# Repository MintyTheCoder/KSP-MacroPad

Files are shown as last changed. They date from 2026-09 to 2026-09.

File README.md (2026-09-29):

# KSP MacroPad

A custom macropad built for Kerbal Space Program, made for Hack Club's Stardance Challenge.

16 macro keys and 2 rotary encoders on a custom PCB, driven by a Seeed XIAO RP2040. The keys don't send keystrokes. They trigger full flight procedures (launch, gravity turn, circularize, rendezvous, suicide burn, an interplanetary autopilot) that a companion KSP mod runs inside the game. The mod talks to the pad over USB serial, and sends state back for per-key RGB LEDs, underglow, and a 128x32 OLED.

The key matrix is read through a resistor ladder on 4 ADC pins instead of 8 GPIO pins, which is what makes everything fit on the XIAO's 11 pins.

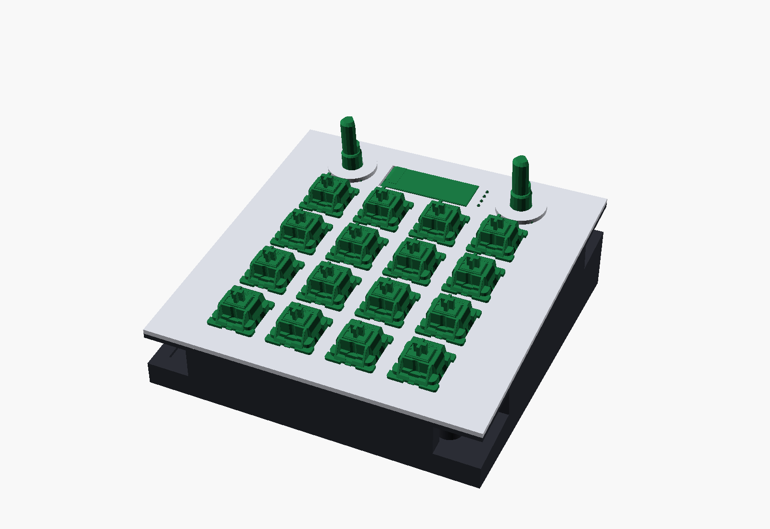
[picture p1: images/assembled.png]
Assembled macropad


## Hardware

- Seeed XIAO RP2040
- 16 MX switches in a 4x4 grid (20 mm pitch), read as an analog matrix on A0 to A3
- 2 EC11 rotary encoders (left on D10/D9, right on D7/D8)
- 20 SK6812 MINI-E RGB LEDs on D6: 16 per-key backlights and 4 underglow
- 0.91" SSD1306 128x32 OLED over I2C (SDA D4, SCL D5)
- 100 x 100 mm 2-layer PCB
- 3D-printed case tilted 7°, with the plate held on by magnets

| | |
|---|---|
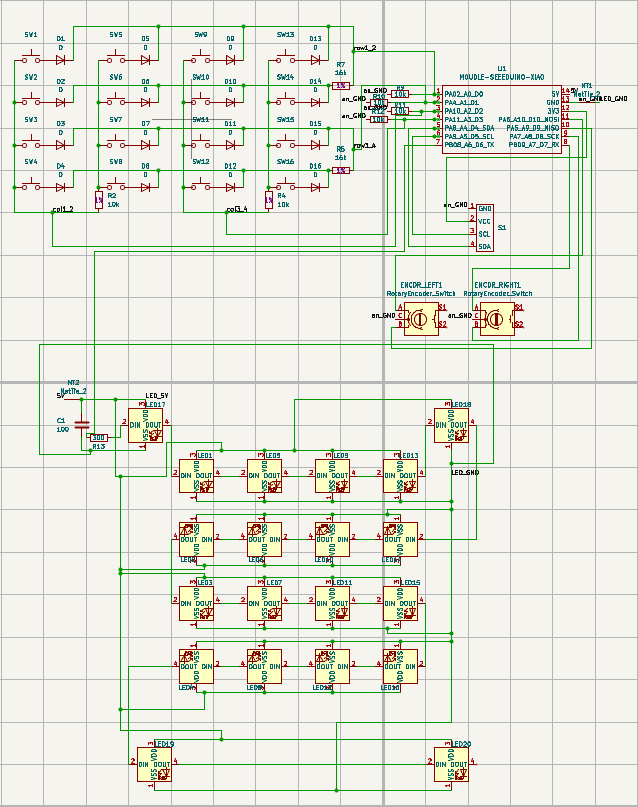
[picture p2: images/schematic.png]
Schematic
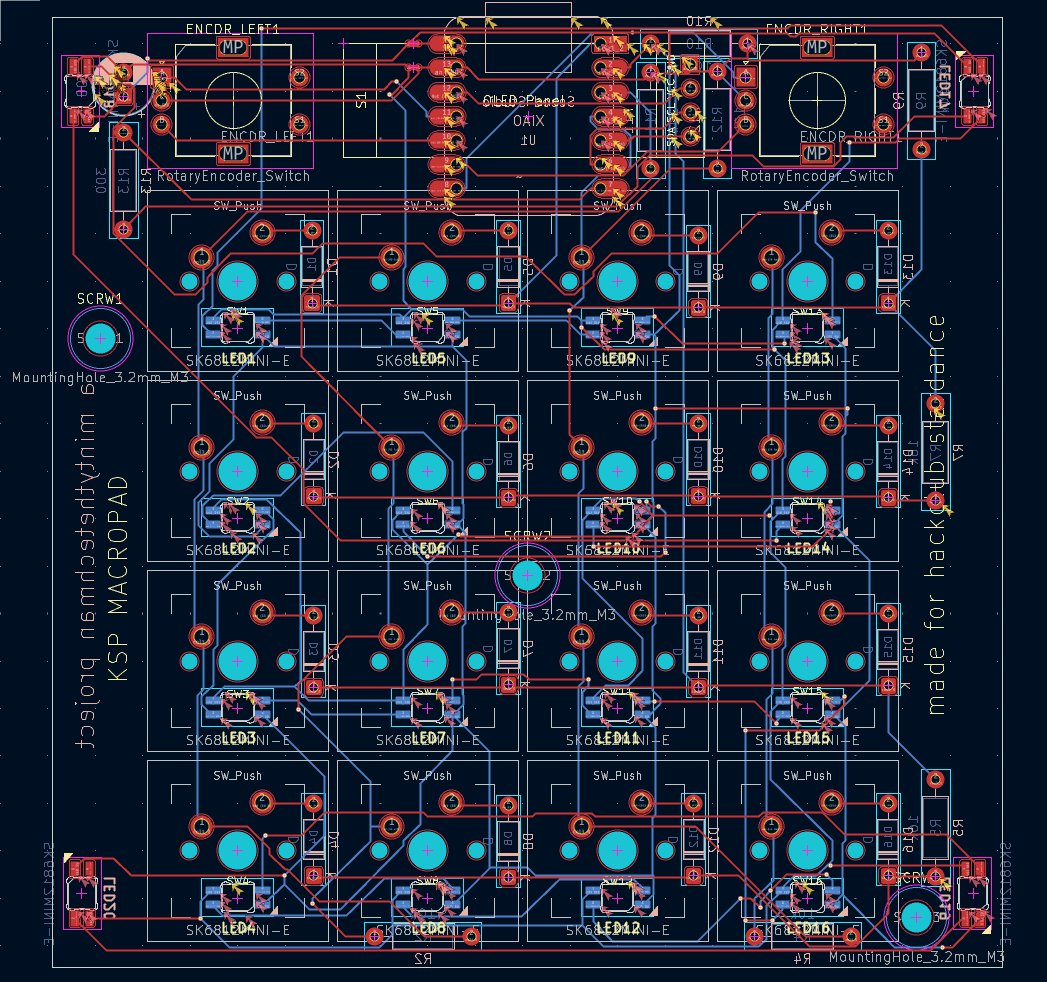
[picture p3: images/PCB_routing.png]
PCB routing
|  |  |
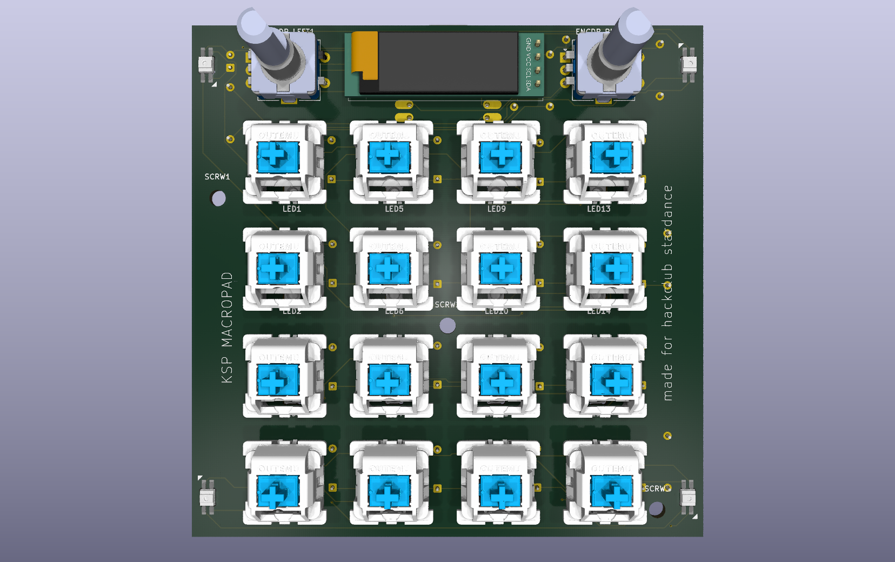
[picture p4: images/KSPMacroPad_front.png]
PCB front
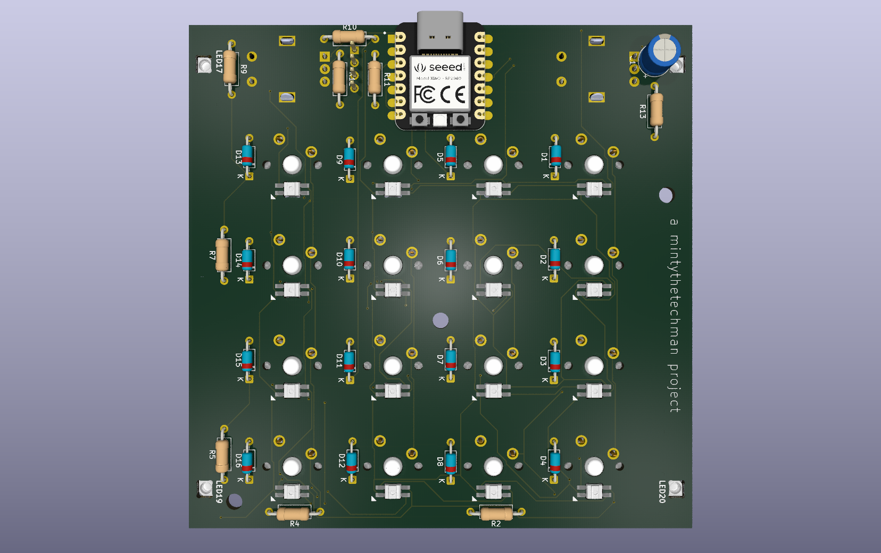
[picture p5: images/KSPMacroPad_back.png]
PCB back
|  |  |

### How the analog matrix works

A normal 4x4 matrix needs 8 pins, and after the encoders, OLED and LEDs there were only 4 left. So each pin carries two lines:

- A2 and A3 each drive two column lines, one straight and one through a 10k resistor.
- A0 and A1 each read two row lines, one straight and one through a 16k resistor, into a 10k pulldown.

The firmware drives one column pin high at a time and reads both row pins. A pressed key puts one of four voltages on its row pin depending on which resistors are in its path:

| Column path | Row path | Row pin voltage |
|---|---|---|
| 10k | 16k | 0.70 to 0.82 V |
| direct | 16k | 0.98 to 1.13 V |
| 10k | direct | 1.28 to 1.45 V |
| direct | direct | 2.62 to 2.85 V |

Those ranges cover 1% resistors across the full 1N4148 diode drop range, and every band has at least 0.15 V of margin to the next, so all 16 keys decode reliably.

## Case

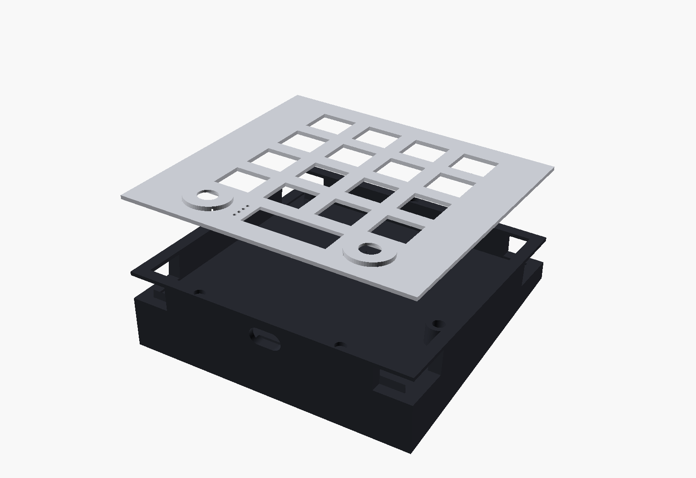
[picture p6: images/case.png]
Case


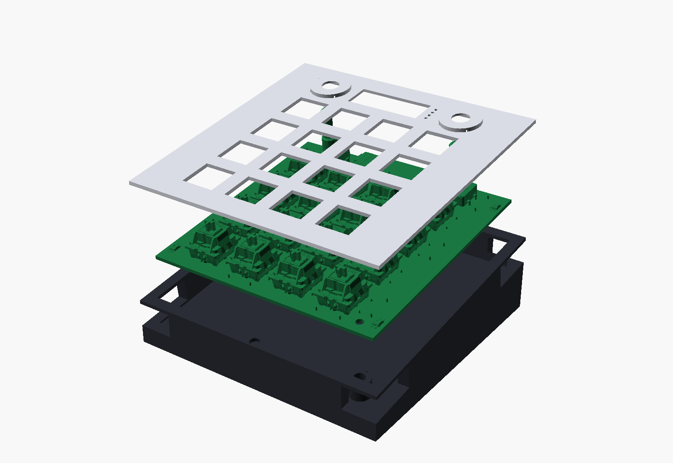
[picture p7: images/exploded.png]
Exploded view


- The board and plate are rotated 7° as one rigid unit on a wedge floor. The bottom stays flat on the desk.
- The plate sits at the MX standard 5.0 mm above the PCB, with 14 mm switch cutouts.
- The encoders come through round holes in raised collars, and the OLED window matches the screen glass.
- The PCB mounts on 3 standoffs with M3 heat-set inserts. The standoffs are perpendicular to the board, with relief notches where parts on the back of the board sit close.
- The plate is held on by 3 pairs of 4 mm magnets, so there are no screws on top.
- The USB-C opening is sized for the plug body and lines up with the tilted connector.
- Underglow notches wrap each corner so the LED light reaches the desk.
- Overall size: 110.4 x 109.8 x 34.2 mm.

The case is fully parametric in [CAD/ksp_macropad_case.scad](CAD/ksp_macropad_case.scad), and it was checked for interference against the real board's STEP model.

## Key Layout

| ID | Macro | ID | Macro |
|---|---|---|---|
| `0x00` | Launch sequence | `0x08` | Docking prep |
| `0x01` | Auto gravity turn | `0x09` | Landing prep |
| `0x02` | Circularize | `0x0A` | Suicide burn arm (hold 1 s) |
| `0x03` | Time warp to next event | `0x0B` | Precision input toggle (encoder mode 2) |
| `0x04` | Intercept | `0x0C` | Transmit science |
| `0x05` | Orbit sync | `0x0D` | Resource monitor |
| `0x06` | Rendezvous prep | `0x0E` | Auxiliary toggle (encoder mode 3) |
| `0x07` | Deorbit burn | `0x0F` | Autopilot |

Macros that fly the vessel queue up: press CIRCULARIZE while AUTO GRAVITY TURN is still flying and it starts as soon as the turn finishes. The OLED shows the active macro and what's queued next.

### Encoder modes

| Mode | Left encoder | Right encoder |
|---|---|---|
| 1: Normal | Throttle | Time warp |
| 2: Precision | Target throttle % | Target heading |
| 3: Auxiliary | Camera zoom | RCS thrust limit % |

## The KSP Mod

The mod ([mod/KSPMacropad](mod/KSPMacropad)) is a C# plugin for KSP 1.12. It:

- finds the pad automatically by listening for its hello packet on every COM port, and reconnects if it's unplugged
- runs all the macros, including a Lambert-solver transfer planner for AUTOPILOT and a closed-loop suicide burn
- drives every key LED and the underglow from live game state (resources, comms, upcoming maneuver nodes, time warp)
- detects MechJeb, Principia, FAR and Kerbalism, and disables the macros that would conflict with them

To install it, build the project in Visual Studio (.NET Framework 4.8) and copy `KSPMacropad.dll` into `GameData/KSPMacropad/Plugins/`. Optional settings go in `KSPMacropad.cfg` next to the DLL:

```
port = COM5
allow_with_mechjeb = true
```

## Serial Protocol

The firmware turns on a second USB CDC data port (in `boot.py`) alongside the REPL console.

**Pad to mod** (6 bytes): `[0x44, type, id, data_hi, data_lo, 0x77]`
- `type 0x01`: key press, `id` = key ID
- `type 0x02`: encoder turn, `id` = `(mode << 4) | encoder` (1 = left, 2 = right), data = signed 16-bit detent steps
- `type 0x03`: hello, sent every second so the mod can find the right port
- `type 0x04`: resync, asks the mod to resend every LED state after a lost connection

**Mod to pad** (5 bytes): `[0x77, id, state, data, 0x44]`
- `0x00` to `0x0F`: key LED state
- `0x10` to `0x13`: underglow state
- `0x14`: heartbeat (the pad shows `NO CONN` after 3 s without one)
- `0x15`: live throttle %
- `0x16`: live warp rate, as `data x 10^(state & 0x0F)`, with bit 7 of `state` set for physics warp
- `0x17` to `0x19`: active macro, next queued macro, queue length

LED state values are defined in `led_states.py` (firmware) and `LEDStates.cs` (mod), and the two have to stay in sync.

## Flashing the Firmware

1. Install [CircuitPython](https://circuitpython.org/board/seeeduino_xiao_rp2040/) on the XIAO RP2040.
2. Copy these libraries from the Adafruit CircuitPython bundle into `CIRCUITPY/lib/`:
   - `neopixel`
   - `adafruit_display_text`
   - `adafruit_displayio_ssd1306`
3. Copy `boot.py`, `code.py` and `led_states.py` from [Firmware/](Firmware/) to the root of `CIRCUITPY`.
4. Power-cycle the board (not just a soft reload) so `boot.py` can turn on the USB data port.

## Bill of Materials

| Qty | Part | Reference | Notes |
|---|---|---|---|
| 1 | Seeed XIAO RP2040 | U1 | |
| 16 | MX switches | SW1 to SW16 | |
| 16 | DSA 1U keycaps | | |
| 16 | 1N4148 diodes, through-hole | D1 to D16 | |
| 20 | SK6812 MINI-E RGB LEDs | LED1 to LED20 | reverse mount |
| 2 | EC11 rotary encoders, 20 mm shaft | ENCDR_LEFT1, ENCDR_RIGHT1 | |
| 1 | 0.91" 128x32 SSD1306 OLED, I2C | S1 | pinout GND, VCC, SCL, SDA |
| 1 | 100 µF electrolytic capacitor | C1 | LED supply |
| 2 | 10k resistor, 1% | R2, R4 | matrix columns |
| 2 | 16k resistor, 1% | R5, R7 | matrix rows |
| 4 | 10k resistor | R9 to R12 | ADC pulldowns |
| 1 | 300 Ω resistor | R13 | LED data line |
| 3 | M3 x 16 mm screws | | PCB to case |
| 3 | M3 x 5 x 4 mm heat-set inserts | | |
| 6 | 4 x 1 mm disc magnets | | plate retention, glued in pairs |
| 1 | PCB | | [production/gerbers.zip](production/gerbers.zip) |
| 1 | Case bottom, 3D printed | | [production/case_bottom.stl](production/case_bottom.stl) |
| 1 | Top plate, 3D printed | | [production/case_top_plate.stl](production/case_top_plate.stl) |

## Repository Layout

- [CAD/](CAD/): OpenSCAD case source, case STEP files, and the full assembled STEP
- [PCB/](PCB/): KiCad 10 project, board STEP, and footprint/3D model libraries
- [Firmware/](Firmware/): CircuitPython firmware
- [mod/](mod/): KSP C# plugin
- [production/](production/): gerbers, printable case STLs, and the firmware files
- [images/](images/): renders and screenshots

## Tools

- KiCad 10
- OpenSCAD
- CircuitPython
- Visual Studio
- Kerbal Space Program

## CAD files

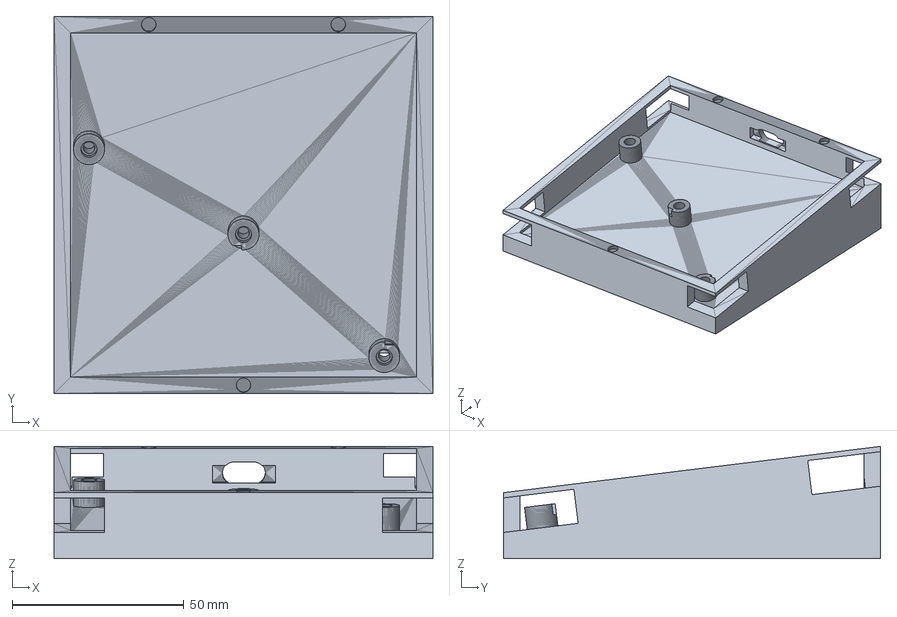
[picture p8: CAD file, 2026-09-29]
CAD/case_bottom.step
110.4 x 109.8 x 32.7 mm

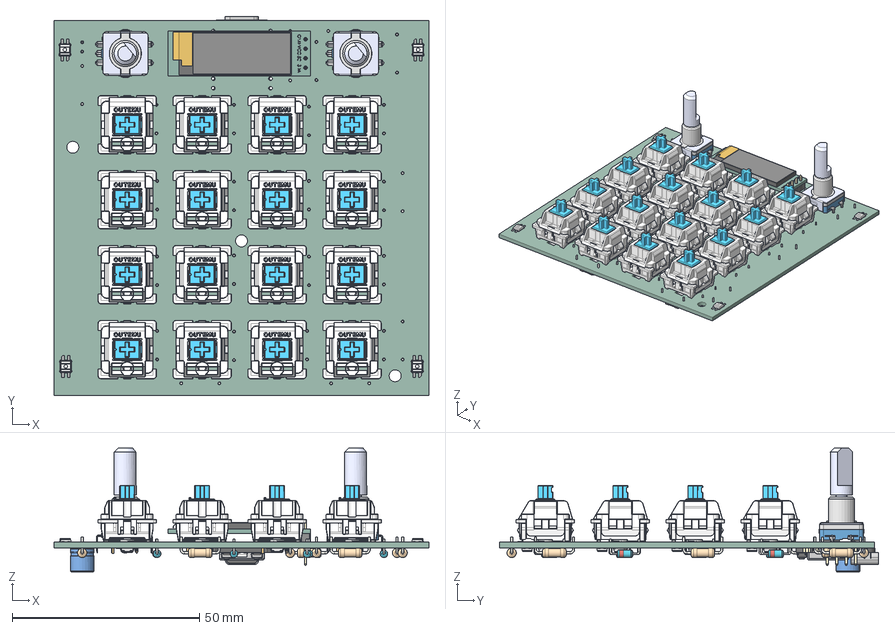
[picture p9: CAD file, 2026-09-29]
PCB/board.step
100.0 x 101.1 x 33.0 mm
Pin1 x 20
Pin2 x 20
Pin3 x 20
Pin4 x 20
BOTT x 16
PIN x 16
SPRIN x 16
CLICK x 16
RET x 16
TOP x 16
128x32-OLED v4
EC11-Base x 2
EC11-Shaft-F x 2
EC11-Housing-THT x 2
D_DO-35_SOD27_P7.62mm_Horizontal x 16
R_Axial_DIN0207_L63mm_D25mm_P1016mm_Horizontal x 9
type-c v2
smd_button v3
DOUT
DIN
VSS
VDD
smd_button v3(Mirror)
CP_Radial_D63mm_P250mm
KSPMacroPad_PCB

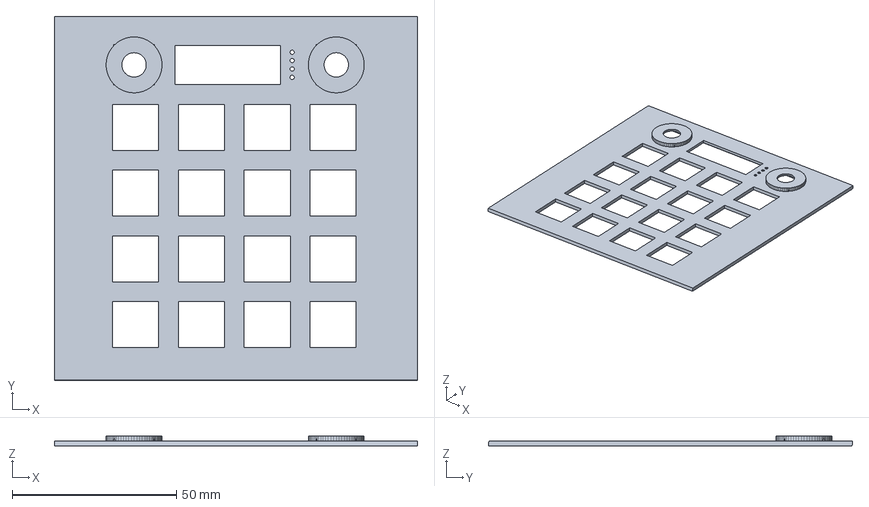
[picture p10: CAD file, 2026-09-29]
CAD/case_top_plate.step
110.4 x 110.8 x 3.10 mm

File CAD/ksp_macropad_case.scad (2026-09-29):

$fn = 64;

tilt = 7;
pcb_w = 100;
pcb_l = 100;
pcb_t = 1.510;
wall_t = 4.8;
gap = 0.4;
standoff_h = 7.5;
plate_t = 1.5;
plate_z0 = pcb_t + 3.5;
floor_front = 6.60;

ox = wall_t + gap;
oy = wall_t + gap + pcb_t * sin(tilt);
yp_front = (-oy - standoff_h * sin(tilt)) / cos(tilt);
oz = floor_front - yp_front * sin(tilt) + standoff_h * cos(tilt);

outer_w = pcb_w + 2 * (gap + wall_t);
cav_y1 = oy + pcb_l * cos(tilt) + gap;
outer_l = cav_y1 + wall_t;
height = 80;

mount_holes = [[5.0, 66.25], [50.0, 41.25], [91.0, 5.25]];
boss_d = 9;
insert_d = 4.7;
insert_depth = 4;
screw_clear_d = 3.4;
screw_below = 14.49;
relief_boxes = [[46.92, 49.08, 29.44, 37.68, -2.67, 2.42], [91.65, 94.35, 9.19, 20.15, -2.69, 2.92]];
relief_margin = 0.4;

switch_centers = [[19.5, 12.25], [19.5, 32.25], [19.5, 52.25], [19.5, 72.25], [39.5, 12.25], [39.5, 32.25], [39.5, 52.25], [39.5, 72.25], [59.5, 12.25], [59.5, 32.25], [59.5, 52.25], [59.5, 72.25], [79.5, 12.25], [79.5, 32.25], [79.5, 52.25], [79.5, 72.25]];
switch_cut = 14.0;
encoder_centers = [[19.0, 91.25], [80.5, 91.25]];
encoder_body = [12.4, 12.3];
encoder_body_top = 5.7;
encoder_collar_d = 17;
encoder_collar_h = 1.6;
encoder_bushing_d = 7.4;

oled_module = [30.06, 68.67, 84.95, 97.55];
oled_pocket_depth = 0.4;
oled_window = [31.5, 63.52, 85.35, 97.15];
oled_pin_x = 67.085;
oled_pin_ys = [87.465, 90.005, 92.545, 95.085];
oled_pin_d = 1.3;

usb_center = [50.11, -2.39];
usb_opening = [12.5, 7.0];
usb_start_y = 100.4;
xiao_pocket = [40.9, 59.3];

magnet_d = 4.2;
magnet_case_depth = 1.5;
magnet_plate_depth = 1.0;

ug_leds = [[1.72, 4.53, 4.81, 10.69, 0.67, 2.46], [1.47, 4.28, 89.31, 95.19, 0.67, 2.46], [95.47, 98.28, 4.81, 10.69, 0.67, 2.46], [95.72, 98.53, 89.31, 95.19, 0.67, 2.46]];
ug_margin = 5;
ug_top = 3.5;

module rigid() {
    translate([ox, oy, oz]) rotate([tilt, 0, 0]) children();
}

function to_yp(world_y, zp) = (world_y - oy + zp * sin(tilt)) / cos(tilt);

module outer_prism() { cube([outer_w, outer_l, height]); }
module cavity_prism() { translate([wall_t, wall_t, -1]) cube([outer_w - 2 * wall_t, outer_l - 2 * wall_t, height + 2]); }
module below_plane(zp) { rigid() translate([-500, -500, zp - 1000]) cube([1000, 1000, 1000]); }
module above_plane(zp) { rigid() translate([-500, -500, zp]) cube([1000, 1000, 1000]); }

module standoffs() {
    intersection() {
        outer_prism();
        rigid() for (h = mount_holes)
            translate([h[0], h[1], -standoff_h - 3]) cylinder(d = boss_d, h = standoff_h + 3);
    }
}

module standoff_cuts() {
    rigid() {
        for (h = mount_holes) {
            translate([h[0], h[1], -insert_depth]) cylinder(d = insert_d, h = insert_depth + 0.01);
            translate([h[0], h[1], -screw_below - 1]) cylinder(d = screw_clear_d, h = screw_below + 1);
        }
        for (b = relief_boxes)
            translate([b[0] - relief_margin, b[2] - relief_margin, b[4] - relief_margin])
                cube([b[1] - b[0] + 2 * relief_margin, b[3] - b[2] + 2 * relief_margin, -b[4] + relief_margin]);
    }
}

module stadium_y(w, h, len) {
    r = h / 2;
    hull() {
        translate([-w / 2 + r, 0, 0]) rotate([-90, 0, 0]) cylinder(r = r, h = len);
        translate([w / 2 - r, 0, 0]) rotate([-90, 0, 0]) cylinder(r = r, h = len);
    }
}

module usb_cuts() {
    rigid() {
        translate([usb_center[0], usb_start_y, usb_center[1]]) stadium_y(usb_opening[0], usb_opening[1], 30);
        translate([xiao_pocket[0], 99.5, -5]) cube([xiao_pocket[1] - xiao_pocket[0], 3, 5]);
    }
}

module underglow_cuts() {
    rigid() for (l = ug_leds) {
        left = l[0] < pcb_w / 2;
        front = l[2] < pcb_l / 2;
        x0 = left ? -30 : l[0] - ug_margin;
        x1 = left ? l[1] + ug_margin : pcb_w + 30;
        y0 = front ? -30 : l[2] - ug_margin;
        y1 = front ? l[3] + ug_margin : pcb_l + 30;
        sx0 = left ? -30 : pcb_w;
        sx1 = left ? 0 : pcb_w + 30;
        sy0 = front ? -30 : pcb_l;
        sy1 = front ? 0 : pcb_l + 30;
        z0 = -standoff_h + 1;
        translate([sx0, y0, z0]) cube([sx1 - sx0, y1 - y0, ug_top - z0]);
        translate([x0, sy0, z0]) cube([x1 - x0, sy1 - sy0, ug_top - z0]);
    }
}

function magnet_positions() = [
    [outer_w / 2, wall_t / 2],
    [outer_w * 0.25, outer_l - wall_t / 2],
    [outer_w * 0.75, outer_l - wall_t / 2]
];

module magnet_cuts(depth, below) {
    rigid() for (m = magnet_positions())
        translate([m[0] - ox, to_yp(m[1], plate_z0), below ? plate_z0 - depth : plate_z0 - 0.01])
            cylinder(d = magnet_d, h = depth + 0.01);
}

module case_bottom() {
    difference() {
        union() {
            difference() {
                intersection() { outer_prism(); below_plane(plate_z0); }
                intersection() { cavity_prism(); above_plane(-standoff_h); }
            }
            standoffs();
        }
        standoff_cuts();
        usb_cuts();
        underglow_cuts();
        magnet_cuts(magnet_case_depth, true);
    }
}

module plate_world() {
    difference() {
        union() {
            intersection() {
                outer_prism();
                rigid() translate([-100, -100, plate_z0]) cube([400, 400, plate_t]);
            }
            rigid() for (e = encoder_centers)
                translate([e[0], e[1], plate_z0 + plate_t - 0.01]) cylinder(d = encoder_collar_d, h = encoder_collar_h + 0.01);
        }
        rigid() {
            for (s = switch_centers)
                translate([s[0] - switch_cut / 2, s[1] - switch_cut / 2, plate_z0 - 1]) cube([switch_cut, switch_cut, plate_t + 2]);
            for (e = encoder_centers) {
                translate([e[0] - encoder_body[0] / 2, e[1] - encoder_body[1] / 2, plate_z0 - 1])
                    cube([encoder_body[0], encoder_body[1], pcb_t + encoder_body_top - plate_z0 + 1]);
                translate([e[0], e[1], plate_z0]) cylinder(d = encoder_bushing_d, h = 10);
            }
            translate([oled_module[0], oled_module[2], plate_z0 - 1])
                cube([oled_module[1] - oled_module[0], oled_module[3] - oled_module[2], oled_pocket_depth + 1]);
            translate([oled_window[0], oled_window[2], plate_z0 - 1])
                cube([oled_window[1] - oled_window[0], oled_window[3] - oled_window[2], plate_t + 2]);
            for (y = oled_pin_ys)
                translate([oled_pin_x, y, plate_z0 - 1]) cylinder(d = oled_pin_d, h = plate_t + 2);
        }
        magnet_cuts(magnet_plate_depth, false);
    }
}

module top_plate_pcb_frame() {
    rotate([-tilt, 0, 0]) translate([-ox, -oy, -oz]) plate_world();
}

part = "bottom";
if (part == "bottom") case_bottom();
else if (part == "plate") top_plate_pcb_frame();
else if (part == "plate_world") plate_world();
else if (part == "print_plate") translate([0, 0, -plate_z0]) top_plate_pcb_frame();

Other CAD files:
production/case_bottom.stl
production/case_top_plate.stl

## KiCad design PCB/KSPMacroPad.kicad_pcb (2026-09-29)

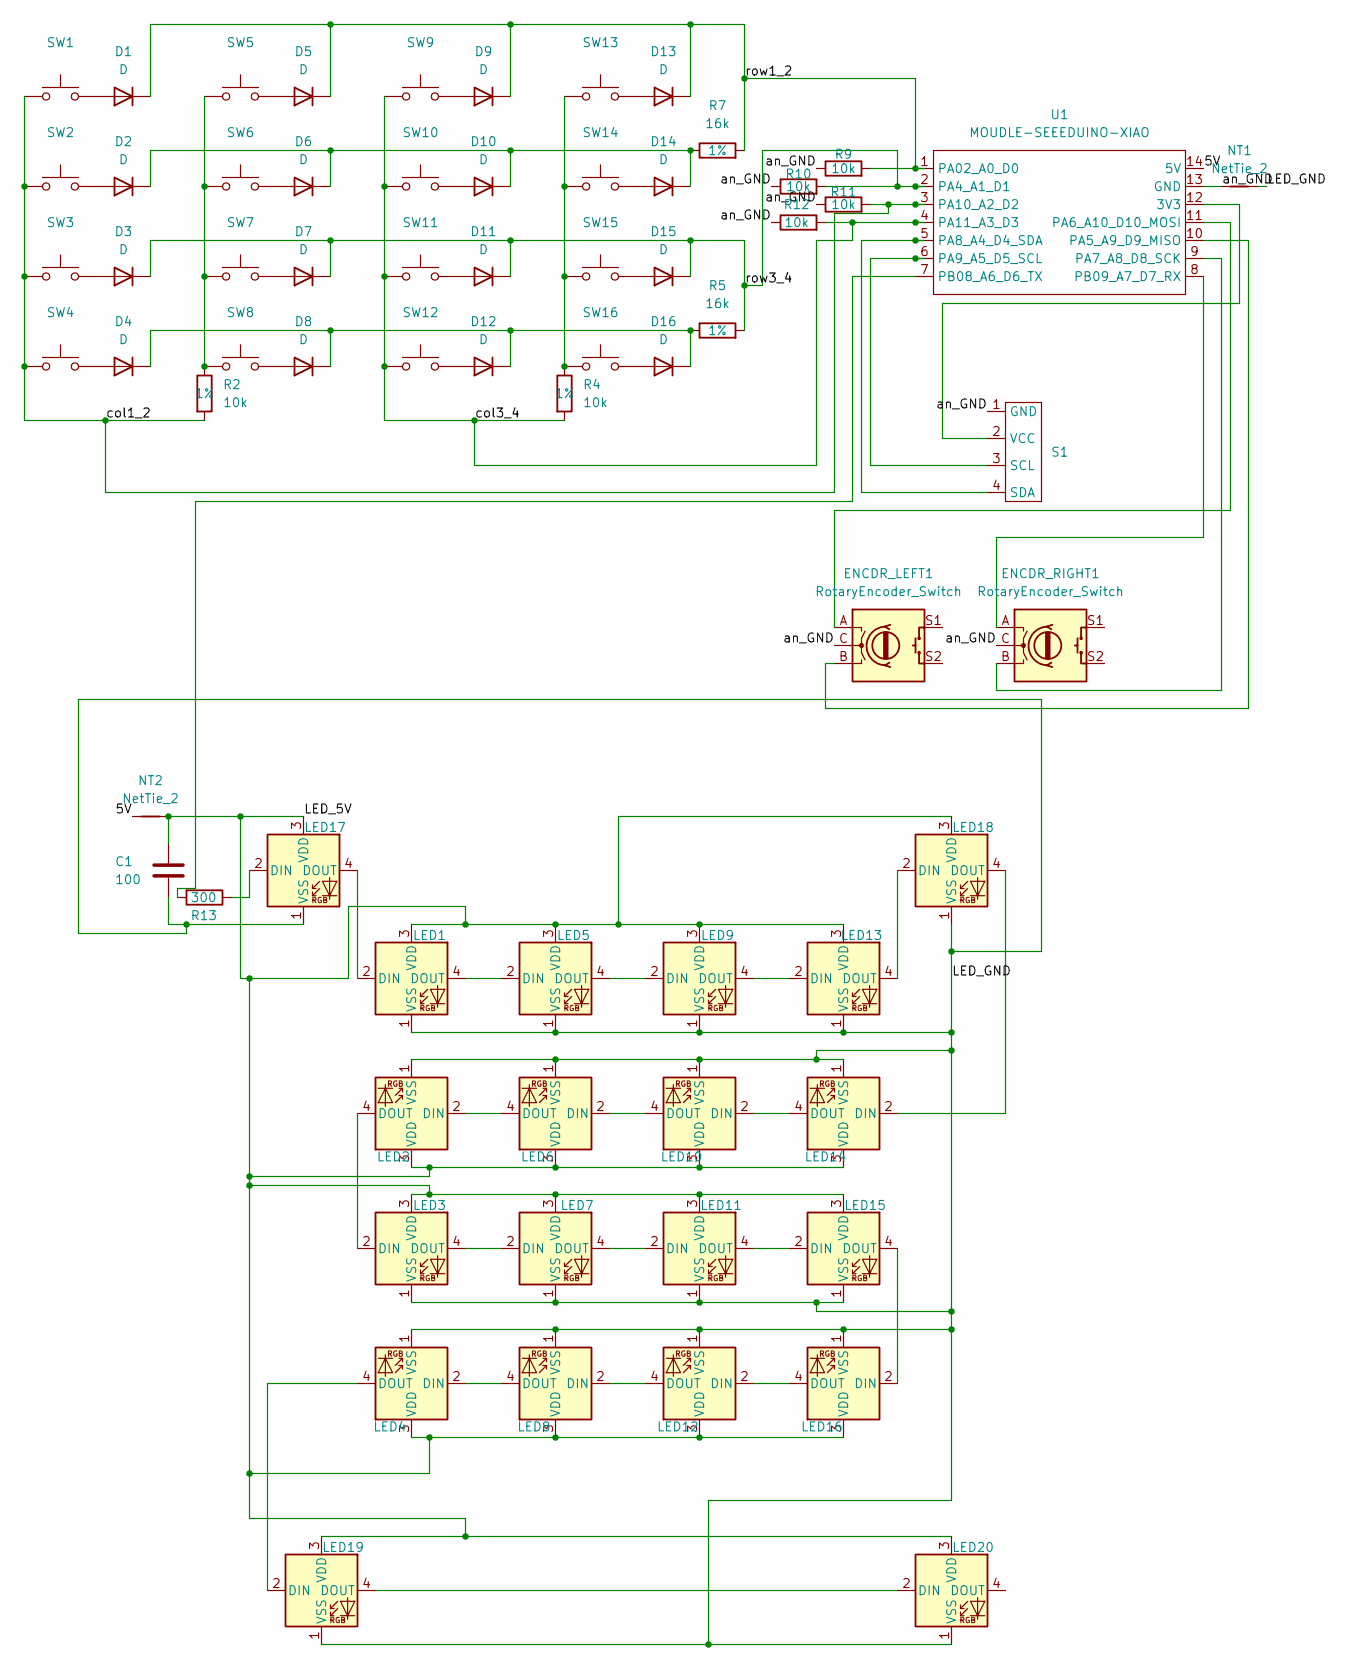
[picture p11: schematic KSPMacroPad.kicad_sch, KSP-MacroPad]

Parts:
C1: 100; CP_Radial_D6.3mm_P2.50mm
D1, D2, D3, D4, D5, D6, D7, D8, D9, D10, D11, D12, D13, D14, D15, D16: D; D_DO-35_SOD27_P7.62mm_Horizontal
ENCDR_LEFT1: RotaryEncoder_Switch; RotaryEncoder_Alps_EC11E-Switch_Vertical_H20mm
ENCDR_RIGHT1: RotaryEncoder_Switch; RotaryEncoder_Alps_EC11E-Switch_Vertical_H20mm
LED1, LED2, LED3, LED4, LED5, LED6, LED7, LED8, LED9, LED10, LED11, LED12, LED13, LED14, LED15, LED16, LED17, LED18, LED19, LED20: SK6812MINI-E; SK6812MINI-E_fixed
NT1, NT2: NetTie_2; NetTie-2_SMD_Pad0.5mm
R2, R4: 10k; R_Axial_DIN0207_L6.3mm_D2.5mm_P10.16mm_Horizontal; Tolerance 1%
R5, R7: 16k; R_Axial_DIN0207_L6.3mm_D2.5mm_P10.16mm_Horizontal; Tolerance 1%
R9, R10, R11, R12: 10k; R_Axial_DIN0207_L6.3mm_D2.5mm_P10.16mm_Horizontal
R13: 300; R_Axial_DIN0207_L6.3mm_D2.5mm_P10.16mm_Horizontal
S1: SSD1306-0.91-OLED-4pin-128x32
SW1, SW2, SW3, SW4, SW5, SW6, SW7, SW8, SW9, SW10, SW11, SW12, SW13, SW14, SW15, SW16: SW_Push; MX-Solderable-1U
U1: MOUDLE-SEEEDUINO-XIAO; XIAO-Generic-Hybrid-14P-2.54-21X17.8MM

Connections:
/5V: NT2.1, U1.14 (5V)
/LED_5V: C1.1, LED1.3 (VDD), LED2.3 (VDD), LED3.3 (VDD), LED4.3 (VDD), LED5.3 (VDD), LED6.3 (VDD), LED7.3 (VDD), LED8.3 (VDD), LED9.3 (VDD), LED10.3 (VDD), LED11.3 (VDD), LED12.3 (VDD), LED13.3 (VDD), LED14.3 (VDD), LED15.3 (VDD), LED16.3 (VDD), LED17.3 (VDD), LED18.3 (VDD), LED19.3 (VDD), LED20.3 (VDD), NT2.2
/LED_GND: C1.2, LED1.1 (VSS), LED2.1 (VSS), LED3.1 (VSS), LED4.1 (VSS), LED5.1 (VSS), LED6.1 (VSS), LED7.1 (VSS), LED8.1 (VSS), LED9.1 (VSS), LED10.1 (VSS), LED11.1 (VSS), LED12.1 (VSS), LED13.1 (VSS), LED14.1 (VSS), LED15.1 (VSS), LED16.1 (VSS), LED17.1 (VSS), LED18.1 (VSS), LED19.1 (VSS), LED20.1 (VSS), NT1.2
/an_GND: ENCDR_LEFT1.C, ENCDR_RIGHT1.C, NT1.1, R9.1, R10.1, R11.1, R12.1, S1.1 (GND), U1.13 (GND)
/col1_2: R2.2, R11.2, SW1.1, SW2.1, SW3.1, SW4.1, U1.3 (PA10_A2_D2)
/col3_4: R4.2, R12.2, SW9.1, SW10.1, SW11.1, SW12.1, U1.4 (PA11_A3_D3)
/row1_2: D1.1 (K), D5.1 (K), D9.1 (K), D13.1 (K), R7.2, R9.2, U1.1 (PA02_A0_D0)
/row3_4: D3.1 (K), D7.1 (K), D11.1 (K), D15.1 (K), R5.2, R10.2, U1.2 (PA4_A1_D1)
unnamed: D1.2 (A), SW1.2
unnamed: D2.2 (A), SW2.2
unnamed: D3.2 (A), SW3.2
unnamed: D4.2 (A), SW4.2
unnamed: D5.2 (A), SW5.2
unnamed: D6.2 (A), SW6.2
unnamed: D7.2 (A), SW7.2
unnamed: D8.2 (A), SW8.2
unnamed: D9.2 (A), SW9.2
unnamed: D10.2 (A), SW10.2
unnamed: D2.1 (K), D6.1 (K), D10.1 (K), D14.1 (K), R7.1
unnamed: D11.2 (A), SW11.2
unnamed: D12.2 (A), SW12.2
unnamed: D4.1 (K), D8.1 (K), D12.1 (K), D16.1 (K), R5.1
unnamed: D13.2 (A), SW13.2
unnamed: D14.2 (A), SW14.2
unnamed: D15.2 (A), SW15.2
unnamed: D16.2 (A), SW16.2
unnamed: LED1.2 (DIN), LED17.4 (DOUT)
unnamed: LED1.4 (DOUT), LED5.2 (DIN)
unnamed: LED2.2 (DIN), LED6.4 (DOUT)
unnamed: LED2.4 (DOUT), LED3.2 (DIN)
unnamed: LED3.4 (DOUT), LED7.2 (DIN)
unnamed: LED4.2 (DIN), LED8.4 (DOUT)
unnamed: LED5.4 (DOUT), LED9.2 (DIN)
unnamed: LED10.2 (DIN), LED14.4 (DOUT)
unnamed: LED6.2 (DIN), LED10.4 (DOUT)
unnamed: LED7.4 (DOUT), LED11.2 (DIN)
unnamed: LED11.4 (DOUT), LED15.2 (DIN)
unnamed: LED12.2 (DIN), LED16.4 (DOUT)
unnamed: LED8.2 (DIN), LED12.4 (DOUT)
unnamed: LED9.4 (DOUT), LED13.2 (DIN)
unnamed: LED13.4 (DOUT), LED18.2 (DIN)
unnamed: LED14.2 (DIN), LED18.4 (DOUT)
unnamed: LED15.4 (DOUT), LED16.2 (DIN)
unnamed: LED17.2 (DIN), R13.1
unnamed: LED4.4 (DOUT), LED19.2 (DIN)
unnamed: LED19.4 (DOUT), LED20.2 (DIN)
unnamed: R2.1, SW5.1, SW6.1, SW7.1, SW8.1
unnamed: R4.1, SW13.1, SW14.1, SW15.1, SW16.1
unnamed: S1.3 (SCL), U1.6 (PA9_A5_D5_SCL)
unnamed: S1.4 (SDA), U1.5 (PA8_A4_D4_SDA)
unnamed: S1.2 (VCC), U1.12 (3V3)
unnamed: ENCDR_LEFT1.B, U1.10 (PA5_A9_D9_MISO)
unnamed: ENCDR_LEFT1.A, U1.11 (PA6_A10_D10_MOSI)
unnamed: ENCDR_RIGHT1.B, U1.9 (PA7_A8_D8_SCK)
unnamed: R13.2, U1.7 (PB08_A6_D6_TX)
unnamed: ENCDR_RIGHT1.A, U1.8 (PB09_A7_D7_RX)

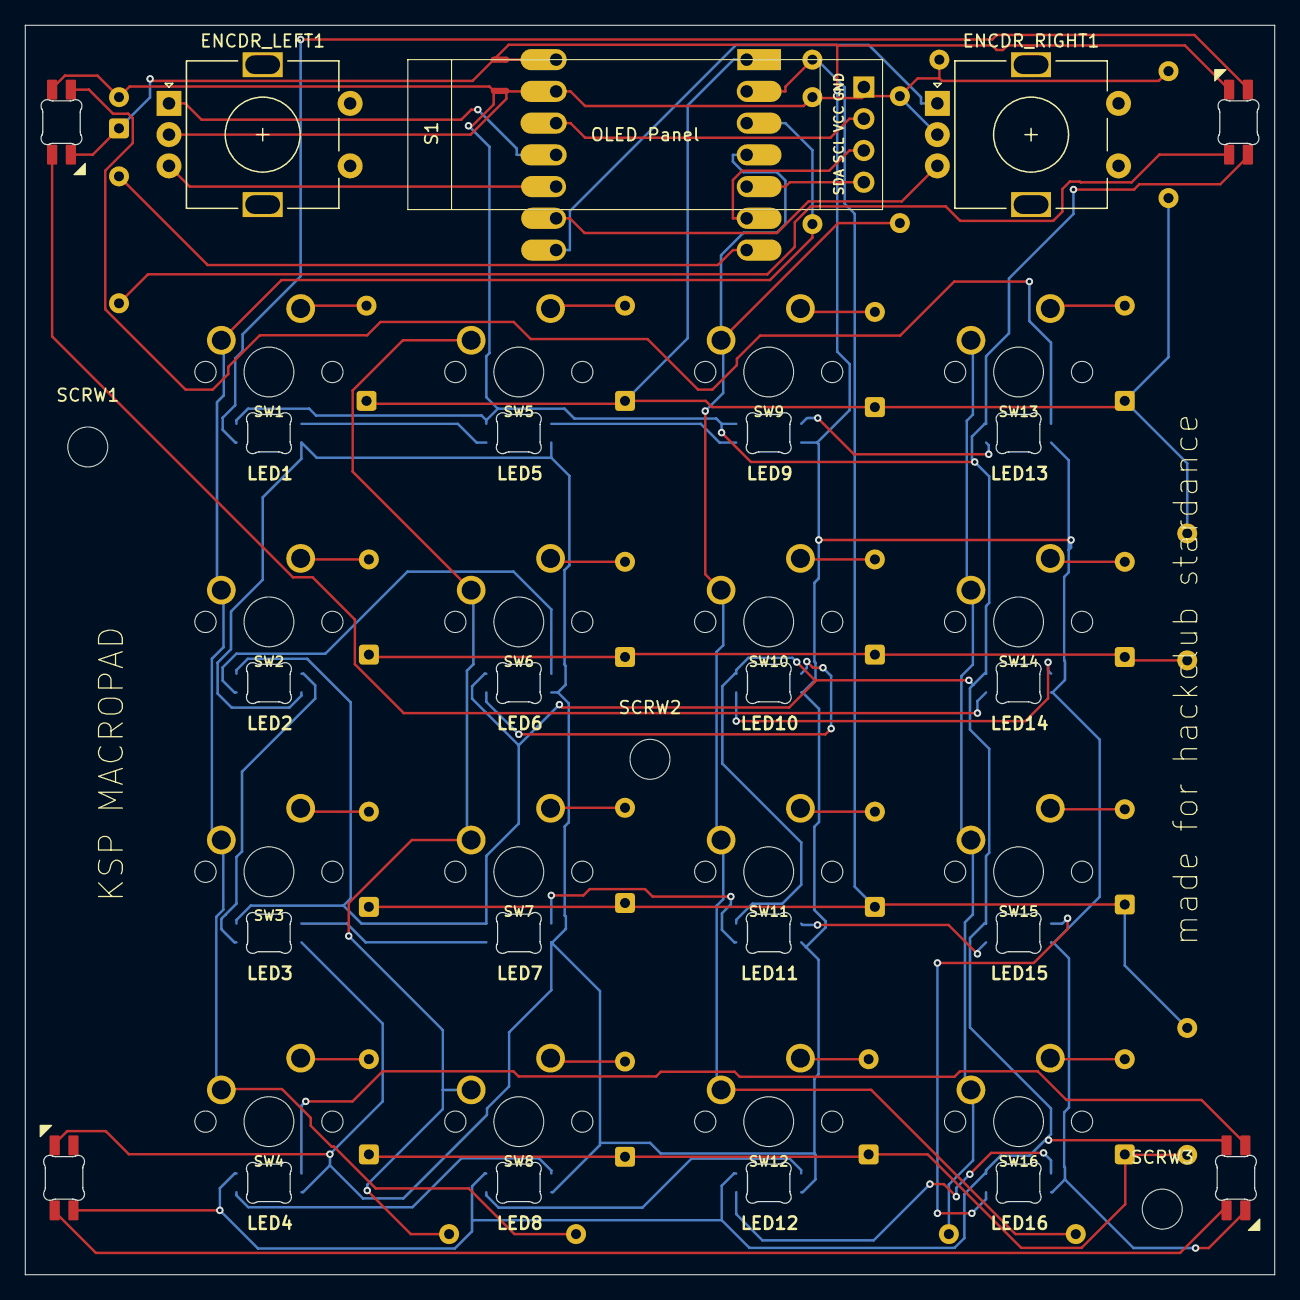
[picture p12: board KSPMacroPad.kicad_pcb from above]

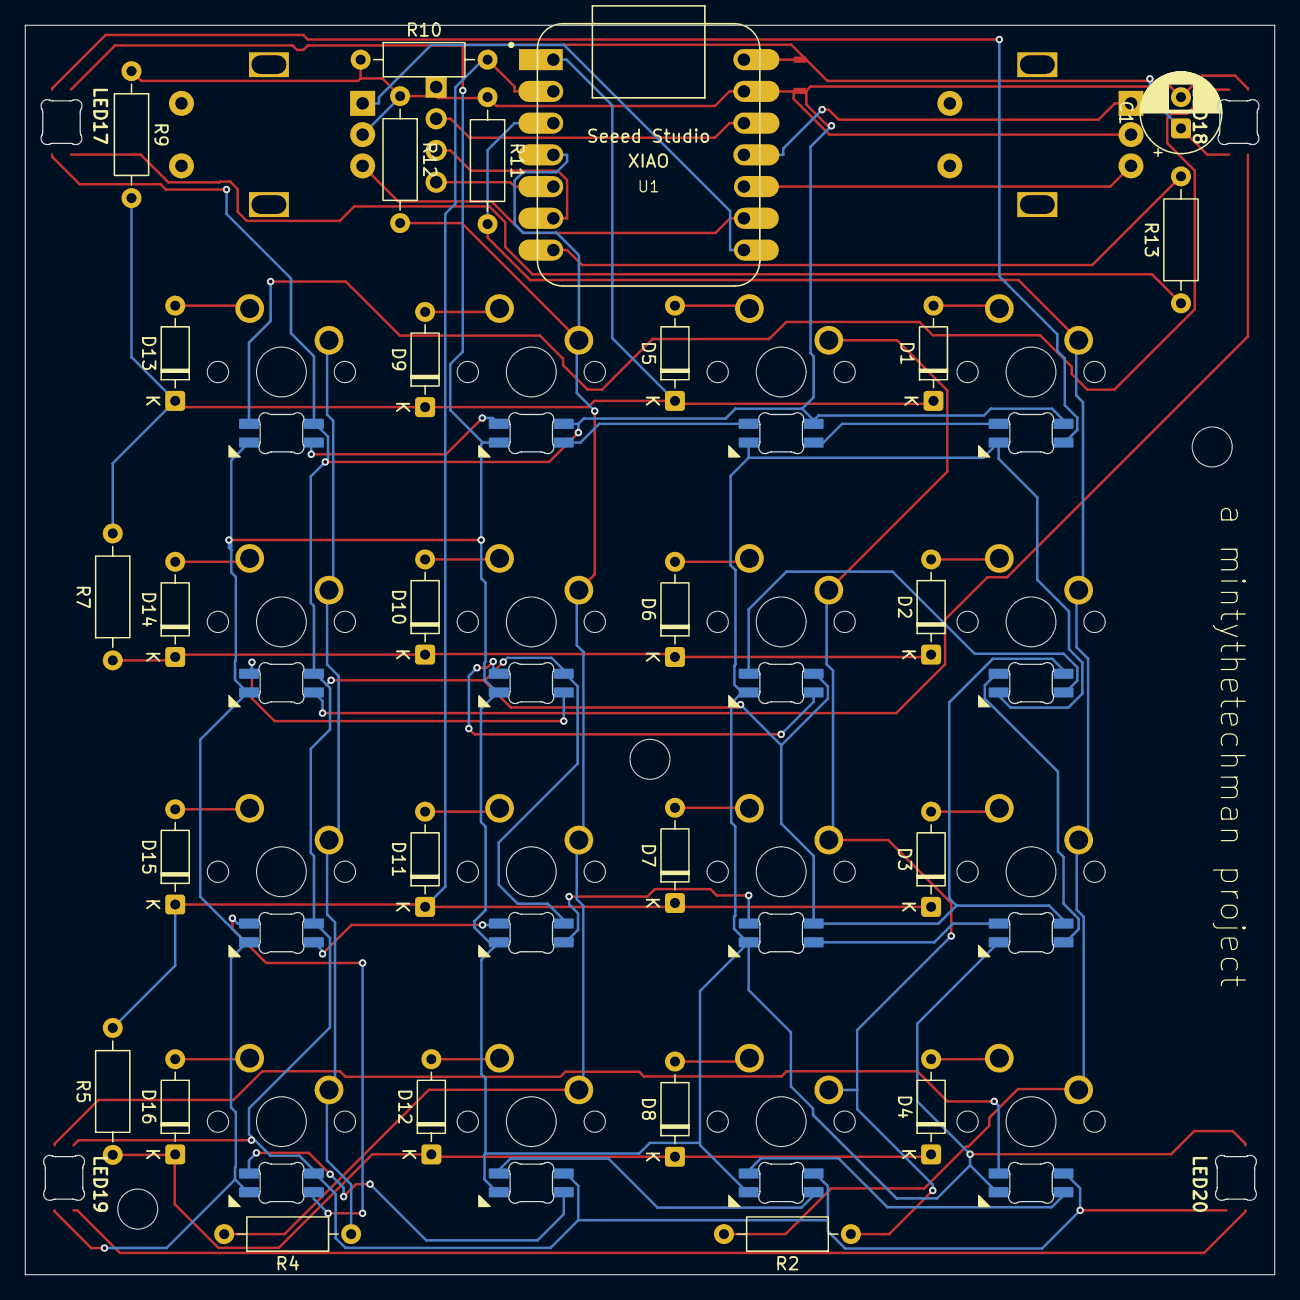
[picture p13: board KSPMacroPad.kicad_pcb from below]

Board: 2 copper layers, 100.0 x 100.0 mm, 71 parts (31 on the bottom side), 56 nets.

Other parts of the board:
SCRW1, SCRW2, SCRW3: MountingHole_3.2mm_M3

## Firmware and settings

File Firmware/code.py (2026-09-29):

# ============================================================================
# KSP MacroPad — Firmware (CircuitPython)
# Version: 0.3.0
# ============================================================================

import time

import board
import analogio
import digitalio
import busio
import rotaryio
import neopixel
import usb_cdc
import displayio
import terminalio
try:
    from i2cdisplaybus import I2CDisplayBus   # CircuitPython 9+
except ImportError:
    I2CDisplayBus = displayio.I2CDisplay      # CircuitPython 8
from adafruit_display_text import label
import adafruit_displayio_ssd1306

from led_states import LEDStates

serial = usb_cdc.data
serial.write_timeout = 0.01   # default is None (block forever), which freezes the pad if nothing reads the port


# ----------------------------------------------------------------------------
# Constants
# ----------------------------------------------------------------------------

# Key matrix (see read_key). Each column pin (A2, A3) feeds two column lines:
# one directly (0 ohm), one through 10k. Each row pin (A0, A1) reads two row
# lines, one directly and one through 16k, into a 10k pulldown. With a
# column pin driven high, a pressed key puts one of four voltages on its row
# pin (1% resistors, 1N4148 drop 0.48-0.65 V, ADC error included):
#   10k column + 16k row   0.70 - 0.82 V
#   0R  column + 16k row   0.98 - 1.13 V
#   10k column + 0R  row   1.28 - 1.45 V
#   0R  column + 0R  row   2.62 - 2.85 V
MATRIX_IDLE_MAX = 0.40
MATRIX_BANDS = (   # (upper edge in volts, column line, row line); line 0 = direct, 1 = through a resistor
    (0.90, 1, 1),
    (1.205, 0, 1),
    (2.00, 1, 0),
    (3.40, 0, 0),
)

DEBOUNCE_COUNT = 4      # consecutive stable reads required before a key registers
COUNTS_PER_DETENT = 4   # raw encoder counts per physical detent click
NUM_LEDS = 20           # total pixels in the NeoPixel chain

LOOP_INTERVAL = 0.01    # seconds per main loop tick

# SUICIDE BURN ARM is the one macro that needs a safety hold, not a tap:
# a plain press/release never fires it, only a continuous hold does.
SUICIDE_ARM_KEY = 0x0A
SUICIDE_ARM_HOLD_SECONDS = 1.0
SUICIDE_ARM_HOLD_TICKS = int(SUICIDE_ARM_HOLD_SECONDS / LOOP_INTERVAL)

OLED_WIDTH = 128
OLED_HEIGHT = 32
OLED_TEXT_COLUMNS = OLED_WIDTH // 6   # terminalio.FONT is 6px wide -> 21 columns

# Boot animation: T-3/2/1 countdown, then a rocket climbing off the top of
# the screen, then the title. LEDs fill along the chain during each part.
BOOT_COUNTDOWN_STEP_SECONDS = 0.35
BOOT_LAUNCH_FRAME_SECONDS = 0.04
BOOT_LAUNCH_PIXELS_PER_FRAME = 2
BOOT_TITLE_SECONDS = 0.8
BOOT_COUNTDOWN_COLOR = (255, 120, 0)
BOOT_LAUNCH_COLOR = (0, 100, 255)

# '#' = rocket body, '*' = exhaust (flickers every frame), '.' = empty
ROCKET_ART = (
    "...##...",
    "..####..",
    "..#..#..",
    "..####..",
    "..####..",
    "..####..",
    ".######.",
    "##.##.##",
    "#..##..#",
    "...**...",
    "..*..*..",
    "...**...",
)

# Reserved inbound IDs outside the key (0x00-0x0F) / underglow (0x10-0x13)
# ranges — same 5-byte packet frame, just new meanings for id/state/data.
HEARTBEAT_ID = 0x14           # mod->pad, sent periodically regardless of state change
THROTTLE_TELEMETRY_ID = 0x15  # data = live throttle % (0-100)
WARP_TELEMETRY_ID = 0x16      # rate = data * 10^(state & 0x0F); state bit 7 set = physics warp
ACTIVE_MACRO_ID = 0x17        # data = key id of the macro flying the vessel, NO_MACRO if none
NEXT_MACRO_ID = 0x18          # data = key id at the head of the mod's queue, NO_MACRO if empty
QUEUE_LENGTH_ID = 0x19        # data = number of queued macros (not counting the active one)
NO_MACRO = 0xFF

# 4-char OLED tags for the macros that can be active/queued.
MACRO_TAGS = {
    0x01: "AGT",
    0x02: "CIRC",
    0x04: "INTC",
    0x05: "SYNC",
    0x07: "DORB",
    0x0A: "SBRN",
    0x0F: "AUTO",
}

# States that pulse instead of holding a solid color. Value = pulse period
# in seconds; faster means more urgent.
PULSING_STATES = {
    (0x0A, LEDStates.SUICIDEBURN_ARMED): 1.2,
    (0x0A, LEDStates.SUICIDEBURN_IMMINENT): 0.4,
    (0x0D, LEDStates.RESOURCE_CRITICAL): 0.5,
    (0x0D, LEDStates.RESOURCE_DEPLETING): 1.0,
    (0x0F, LEDStates.AUTOPILOT_EXECUTING): 1.6,
    (0x10, LEDStates.UNDERGLOW_CRITICAL_RESOURCE): 0.5,
    (0x10, LEDStates.UNDERGLOW_COMMS_LOST): 1.0,
    (0x10, LEDStates.UNDERGLOW_MANEUVER_IMMINENT): 1.0,
}
PULSE_MIN_BRIGHTNESS = 0.15
PULSE_FRAME_INTERVAL = 0.03

# RENDEZVOUS PREP's data byte is closing speed (0 = holding or separating,
# 255 = the mod's max). The key blends from its state color toward this
# as the approach gets faster.
RENDEZVOUS_FAST_COLOR = (255, 0, 0)

HEARTBEAT_TIMEOUT = 3.0   # seconds since last heartbeat before we call it disconnected

# Pad -> mod hello, sent periodically so the mod can tell this data port
# apart from the REPL console port (and anything else plugged in).
PAD_HELLO_TYPE = 0x03
PAD_HELLO_INTERVAL = 1.0
PAD_RESYNC_TYPE = 0x04   # "resend everything" - sent when the heartbeat comes back after a lapse


# ----------------------------------------------------------------------------
# Hardware setup
# ----------------------------------------------------------------------------

row_pins = [analogio.AnalogIn(board.A0), analogio.AnalogIn(board.A1)]
col_drives = [digitalio.DigitalInOut(board.A2), digitalio.DigitalInOut(board.A3)]   # high-Z until scanned

left_enc = rotaryio.IncrementalEncoder(board.D10, board.D9)
right_enc = rotaryio.IncrementalEncoder(board.D7, board.D8)

pixels = neopixel.NeoPixel(board.D6, NUM_LEDS, auto_write=False)

displayio.release_displays()
_i2c = busio.I2C(board.D5, board.D4)   # SCL, SDA - the PCB routes the OLED to D5/D4 (D0/D1 are A0/A1, the matrix)
_display_bus = I2CDisplayBus(_i2c, device_address=0x3C)
display = adafruit_displayio_ssd1306.SSD1306(_display_bus, width=OLED_WIDTH, height=OLED_HEIGHT)


# ----------------------------------------------------------------------------
# Runtime state
# ----------------------------------------------------------------------------

encoder_mode = 1   # 1 = normal, 2 = precision input, 3 = aux mode

# Locally-dialed target values for modes 2/3 (pre-commit, display-only —
# not the mod's authoritative state). Indexed by mode.
dial_targets = {
    2: {"left": 0, "right": 0},   # left = target throttle % (0-100), right = target heading deg (0-359)
    3: {"left": 0, "right": 0},   # left = camera zoom (unclamped), right = RCS thrust limiter % (0-100)
}

# Mode 1 live telemetry, confirmed by the mod (see THROTTLE/WARP_TELEMETRY_ID
# below) — None until the first packet of that type arrives.
live_throttle = None
live_warp = None

# Macro queue as reported by the mod (see ACTIVE_MACRO_ID etc.). Cleared
# on disconnect since the mod can't be flying anything we can see.
active_macro = None
next_macro = None
queued_count = 0

_last_heartbeat = None      # time.monotonic() of the last heartbeat, None = never seen one
_last_connected = False     # last displayed connection state, so update_display only fires on change

_stable_key = None
_stable_count = 0
_reported_key = None

_left_accum = 0
_right_accum = 0
_left_last = left_enc.position
_right_last = right_enc.position

_in_buf = bytearray()
_last_hello = 0.0

_pixel_base = [(0, 0, 0)] * NUM_LEDS   # color each pixel should show at full brightness
_pixel_pulse = [None] * NUM_LEDS       # pulse period in seconds, None = solid
_last_pulse_frame = 0.0


# ----------------------------------------------------------------------------
# Key matrix mapping
# ----------------------------------------------------------------------------
# Key ids run left to right, top to bottom: the top row (nearest the OLED) is
# 0x00-0x03, the bottom row 0x0C-0x0F. read_key returns row * 4 + col.


# ----------------------------------------------------------------------------
# LED chain mapping
# ----------------------------------------------------------------------------
# Physical NeoPixel chain order -> key_id it lights up for.
# None = underglow pixel (not tied to a specific key).
# The chain snakes across the rows: top row left to right, second row right
# to left, and so on, with the corner underglow LEDs at positions 0, 5, 18, 19.
LED_CHAIN_TO_KEY = [
    None,
    0x00, 0x01, 0x02, 0x03,
    None,
    0x07, 0x06, 0x05, 0x04,
    0x08, 0x09, 0x0A, 0x0B,
    0x0F, 0x0E, 0x0D, 0x0C,
    None, None,
]

# Reverse lookup: key_id -> chain index
KEY_TO_LED_CHAIN = {key: i for i, key in enumerate(LED_CHAIN_TO_KEY) if key is not None}

# Chain indices reserved for underglow (not mapped to any key)
UNDERGLOW_CHAIN_INDICES = [i for i, key in enumerate(LED_CHAIN_TO_KEY) if key is None]


# ----------------------------------------------------------------------------
# LED state -> color table
# ----------------------------------------------------------------------------
# Keyed by (led_id, state). led_id 0x10-0x13 (underglow zones) all share the
# 0x10 entries — see apply_led_update's lookup_id collapsing.
STATE_COLORS = {
    (0x00, LEDStates.LAUNCH_IDLE): (0, 0, 0),
    (0x00, LEDStates.LAUNCH_EXECUTING): (0, 100, 255),
    (0x00, LEDStates.LAUNCH_COMPLETE): (0, 255, 0),

    (0x01, LEDStates.AGT_IDLE): (0, 0, 0),
    (0x01, LEDStates.AGT_ACTIVE): (0, 100, 255),

    (0x02, LEDStates.CIRC_IDLE): (0, 0, 0),
    (0x02, LEDStates.CIRC_UNAVAILABLE): (255, 0, 0),
    (0x02, LEDStates.CIRC_CALCULATING): (255, 180, 0),
    (0x02, LEDStates.CIRC_WARPING): (0, 255, 255),
    (0x02, LEDStates.CIRC_COMPLETE): (0, 255, 0),

    (0x03, LEDStates.TIMEACCEL_IDLE): (0, 0, 0),
    (0x03, LEDStates.TIMEACCEL_UNAVAILABLE): (255, 0, 0),
    (0x03, LEDStates.TIMEACCEL_WARPING): (0, 255, 255),

    (0x04, LEDStates.INTERCEPT_IDLE): (0, 0, 0),
    (0x04, LEDStates.INTERCEPT_CALCULATING): (255, 180, 0),
    (0x04, LEDStates.INTERCEPT_SOLUTION): (0, 255, 0),
    (0x04, LEDStates.INTERCEPT_INSUFFICIENT_DV): (255, 0, 0),

    (0x05, LEDStates.ORBSYNC_IDLE): (0, 0, 0),
    (0x05, LEDStates.ORBSYNC_CALCULATING): (255, 180, 0),
    (0x05, LEDStates.ORBSYNC_EXECUTING): (0, 100, 255),
    (0x05, LEDStates.ORBSYNC_COMPLETE): (0, 255, 0),

    (0x06, LEDStates.RENDEZVOUS_IDLE): (0, 0, 0),
    (0x06, LEDStates.RENDEZVOUS_ACTIVE): (0, 100, 255),
    (0x06, LEDStates.RENDEZVOUS_IN_RANGE): (0, 255, 0),

    (0x07, LEDStates.DEORBIT_IDLE): (0, 0, 0),
    (0x07, LEDStates.DEORBIT_UNAVAILABLE): (255, 0, 0),
    (0x07, LEDStates.DEORBIT_PLANNED): (255, 180, 0),
    (0x07, LEDStates.DEORBIT_WARPING): (0, 255, 255),
    (0x07, LEDStates.DEORBIT_BURNING): (0, 100, 255),

    (0x08, LEDStates.DOCK_IDLE): (0, 0, 0),
    (0x08, LEDStates.DOCK_ACTIVE): (0, 100, 255),
    (0x08, LEDStates.DOCK_TARGET_ACQUIRED): (0, 200, 255),
    (0x08, LEDStates.DOCK_READY): (0, 255, 0),

    (0x09, LEDStates.LANDING_IDLE): (0, 0, 0),
    (0x09, LEDStates.LANDING_CONFIGURING): (255, 180, 0),
    (0x09, LEDStates.LANDING_COMPLETE): (0, 255, 0),

    (0x0A, LEDStates.SUICIDEBURN_IDLE): (0, 0, 0),
    (0x0A, LEDStates.SUICIDEBURN_ARMED): (255, 90, 0),
    (0x0A, LEDStates.SUICIDEBURN_IMMINENT): (255, 0, 0),
    (0x0A, LEDStates.SUICIDEBURN_BURNING): (0, 100, 255),

    (0x0C, LEDStates.SCIENCE_IDLE): (0, 0, 0),
    (0x0C, LEDStates.SCIENCE_UNAVAILABLE): (255, 0, 0),
    (0x0C, LEDStates.SCIENCE_TRANSMITTING): (0, 100, 255),
    (0x0C, LEDStates.SCIENCE_COMPLETE): (0, 255, 0),

    (0x0D, LEDStates.RESOURCE_IDLE): (0, 0, 0),
    (0x0D, LEDStates.RESOURCE_NOMINAL): (0, 255, 0),
    (0x0D, LEDStates.RESOURCE_LOW): (255, 180, 0),
    (0x0D, LEDStates.RESOURCE_VERYLOW): (255, 90, 0),
    (0x0D, LEDStates.RESOURCE_CRITICAL): (255, 0, 0),
    (0x0D, LEDStates.RESOURCE_DEPLETING): (255, 0, 0),

    (0x0F, LEDStates.AUTOPILOT_IDLE): (0, 0, 0),
    (0x0F, LEDStates.AUTOPILOT_IMPOSSIBLE): (255, 0, 0),
    (0x0F, LEDStates.AUTOPILOT_READY): (0, 255, 0),
    (0x0F, LEDStates.AUTOPILOT_PLANNING): (255, 180, 0),
    (0x0F, LEDStates.AUTOPILOT_EXECUTING): (0, 100, 255),

    (0x10, LEDStates.UNDERGLOW_IDLE): (0, 0, 0),
    (0x10, LEDStates.UNDERGLOW_CONNECTED_NOVESSEL): (40, 40, 40),
    (0x10, LEDStates.UNDERGLOW_LAUNCHPAD): (255, 180, 0),
    (0x10, LEDStates.UNDERGLOW_ASCENT): (0, 100, 255),
    (0x10, LEDStates.UNDERGLOW_STABLE_ORBIT): (0, 255, 0),
    (0x10, LEDStates.UNDERGLOW_TIMEWARP): (0, 255, 255),
    (0x10, LEDStates.UNDERGLOW_MANEUVER_IMMINENT): (255, 90, 0),
    (0x10, LEDStates.UNDERGLOW_LANDING): (255, 180, 0),
    (0x10, LEDStates.UNDERGLOW_AUTOPILOT): (150, 0, 255),
    (0x10, LEDStates.UNDERGLOW_CRITICAL_RESOURCE): (255, 0, 0),
    (0x10, LEDStates.UNDERGLOW_COMMS_LOST): (255, 0, 0),
}


# ----------------------------------------------------------------------------
# Key matrix scanning
# ----------------------------------------------------------------------------

def read_voltage(pin):
    return pin.value / 65535 * 3.3


def decode_matrix(col_pin, row_pin, voltage):
    """(row, col) of the key closed between the driven col_pin and row_pin,
    from that row pin's voltage, or None if nothing is pressed there."""
    if voltage < MATRIX_IDLE_MAX:
        return None
    for edge, col_line, row_line in MATRIX_BANDS:
        if voltage < edge:
            return row_pin * 2 + row_line, col_pin * 2 + col_line
    return None


def read_key():
    """Drive each column pin high in turn and read both row pins. The matrix
    has no other voltage source, so an undriven column pin reads nothing.
    Single keys only - two keys on the same row pin under the same driven
    column add their currents and read as a different key."""
    found = None
    for c, drive in enumerate(col_drives):
        drive.switch_to_output(value=True)
        for r, pin in enumerate(row_pins):
            hit = decode_matrix(c, r, read_voltage(pin))
            if hit is not None and found is None:
                found = hit
        drive.switch_to_input()
    if found is None:
        return None
    row, col = found
    return row * 4 + col


def poll_key():
    """Debounced key read. Returns a key_id only on a new, stable press.

    SUICIDE_ARM_KEY is the exception: it needs SUICIDE_ARM_HOLD_TICKS of
    continuous hold (not just DEBOUNCE_COUNT) before it fires. Releasing
    early resets _stable_count back to 0 on the next differing read, so
    an early release simply never reaches the threshold — no separate
    cancel signal needed."""
    global _stable_key, _stable_count, _reported_key

    current = read_key()

    if current == _stable_key:
        _stable_count += 1
    else:
        _stable_key = current
        _stable_count = 1

    required = SUICIDE_ARM_HOLD_TICKS if _stable_key == SUICIDE_ARM_KEY else DEBOUNCE_COUNT
    if _stable_count < required:
        return None

    if _stable_key != _reported_key:
        _reported_key = _stable_key
        if _stable_key is not None:
            return _stable_key

    return None


# ----------------------------------------------------------------------------
# Encoder polling
# ----------------------------------------------------------------------------

def poll_encoders():
    """Accumulate raw encoder counts and emit whole detent steps."""
    global _left_last, _right_last, _left_accum, _right_accum

    left_pos = left_enc.position
    right_pos = right_enc.position

    _left_accum += left_pos - _left_last
    _right_accum += right_pos - _right_last

    _left_last = left_pos
    _right_last = right_pos

    left_steps = _left_accum // COUNTS_PER_DETENT
    right_steps = _right_accum // COUNTS_PER_DETENT

    _left_accum -= left_steps * COUNTS_PER_DETENT
    _right_accum -= right_steps * COUNTS_PER_DETENT

    return left_steps, right_steps


# ----------------------------------------------------------------------------
# Serial protocol — outbound (pad -> mod)
# ----------------------------------------------------------------------------
# Packet format: [0x44, msg_type, id, data_hi, data_lo, 0x77]

def send_packet(packet):
    """Write only when a host has the port open (DTR set); otherwise the
    bytes have nowhere to go."""
    if serial.connected:
        serial.write(packet)


def send_key_packet(key_id):
    send_packet(bytes([0x44, 0x01, key_id, 0x00, 0x01, 0x77]))


def send_hello():
    send_packet(bytes([0x44, PAD_HELLO_TYPE, 0x00, 0x00, 0x00, 0x77]))


def send_resync():
    send_packet(bytes([0x44, PAD_RESYNC_TYPE, 0x00, 0x00, 0x00, 0x77]))


def send_encoder_packet(encoder_id, steps):
    steps = max(-32768, min(32767, steps))
    hi = (steps >> 8) & 0xFF
    lo = steps & 0xFF
    send_packet(bytes([0x44, 0x02, encoder_id, hi, lo, 0x77]))


# ----------------------------------------------------------------------------
# Serial protocol — inbound (mod -> pad)
# ----------------------------------------------------------------------------
# Packet format: [0x77, id, state, data, 0x44] — shared frame for LED
# updates, telemetry (THROTTLE/WARP_TELEMETRY_ID), and HEARTBEAT_ID.

def read_inbound_packet():
    """Pull one complete inbound packet off the serial buffer, if available."""
    global _in_buf
    if serial.in_waiting > 0:
        _in_buf += serial.read(serial.in_waiting)

    while len(_in_buf) >= 5:
        if _in_buf[0] != 0x77:
            _in_buf = _in_buf[1:]
            continue
        if _in_buf[4] != 0x44:
            _in_buf = _in_buf[1:]
            continue
        packet_id, state, data = _in_buf[1], _in_buf[2], _in_buf[3]
        _in_buf = _in_buf[5:]
        return packet_id, state, data

    return None


def _blend(a, b, t):
    return tuple(int(a[i] + (b[i] - a[i]) * t) for i in range(3))


def _scale(color, k):
    return tuple(int(c * k) for c in color)


def apply_led_update(led_id, state, data):
    """Resolve an LED packet to a color and write it to the pixel chain."""
    lookup_id = 0x10 if 0x10 <= led_id <= 0x13 else led_id
    color = STATE_COLORS.get((lookup_id, state), (0, 0, 0))

    if lookup_id == 0x06 and state != LEDStates.RENDEZVOUS_IDLE:
        color = _blend(color, RENDEZVOUS_FAST_COLOR, data / 255)

    if led_id in KEY_TO_LED_CHAIN:
        index = KEY_TO_LED_CHAIN[led_id]
    elif 0x10 <= led_id <= 0x13:
        index = UNDERGLOW_CHAIN_INDICES[led_id - 0x10]
    else:
        return

    _pixel_base[index] = color
    _pixel_pulse[index] = PULSING_STATES.get((lookup_id, state))
    pixels[index] = color
    pixels.show()


def animate_pulses(now):
    """Triangle-wave brightness on every pixel in a pulsing state."""
    global _last_pulse_frame
    if now - _last_pulse_frame < PULSE_FRAME_INTERVAL:
        return
    _last_pulse_frame = now
    changed = False
    for i in range(NUM_LEDS):
        period = _pixel_pulse[i]
        if period is None:
            continue
        phase = (now % period) / period
        wave = 1 - abs(2 * phase - 1)
        pixels[i] = _scale(_pixel_base[i], PULSE_MIN_BRIGHTNESS + (1 - PULSE_MIN_BRIGHTNESS) * wave)
        changed = True
    if changed:
        pixels.show()


def clear_leds():
    for i in range(NUM_LEDS):
        _pixel_base[i] = (0, 0, 0)
        _pixel_pulse[i] = None
    pixels.fill((0, 0, 0))
    pixels.show()


# ----------------------------------------------------------------------------
# OLED display
# ----------------------------------------------------------------------------
# Line 1: connection status (from HEARTBEAT_ID) + current encoder mode.
# Line 2: mode 1 shows mod-confirmed live throttle/warp (THROTTLE/WARP_
# TELEMETRY_ID) once received; modes 2/3 show the locally-dialed target
# values (pre-commit, not yet sent to the mod as a "final" value).

def _fill_led_chain(fraction, color):
    """Light the first `fraction` of the chain (in chain order) with color."""
    lit = int(NUM_LEDS * fraction)
    for i in range(NUM_LEDS):
        pixels[i] = color if i < lit else (0, 0, 0)
    pixels.show()


def _make_rocket():
    """Build the rocket TileGrid from ROCKET_ART. Returns (tilegrid, palette);
    palette[2] is the exhaust color, toggled per frame for flicker."""
    height = len(ROCKET_ART)
    width = len(ROCKET_ART[0])
    bitmap = displayio.Bitmap(width, height, 3)
    palette = displayio.Palette(3)
    palette[0] = 0x000000
    palette[1] = 0xFFFFFF
    palette[2] = 0xFFFFFF
    palette.make_transparent(0)
    for y, row in enumerate(ROCKET_ART):
        for x, ch in enumerate(row):
            if ch == "#":
                bitmap[x, y] = 1
            elif ch == "*":
                bitmap[x, y] = 2
    return displayio.TileGrid(bitmap, pixel_shader=palette), palette


def show_boot_animation():
    group = displayio.Group()
    display.root_group = group

    # T-3, T-2, T-1 at 2x scale (12px per char), LEDs filling amber.
    countdown = label.Label(terminalio.FONT, text="", scale=2, x=(OLED_WIDTH - 3 * 12) // 2, y=16)
    group.append(countdown)
    for i, n in enumerate((3, 2, 1)):
        countdown.text = "T-{}".format(n)
        _fill_led_chain((i + 1) / 3, BOOT_COUNTDOWN_COLOR)
        time.sleep(BOOT_COUNTDOWN_STEP_SECONDS)
    group.remove(countdown)

    # Liftoff: rocket climbs from below the screen until it's off the top,
    # LEDs refilling blue along the chain as it goes.
    rocket, palette = _make_rocket()
    rocket.x = (OLED_WIDTH - len(ROCKET_ART[0])) // 2
    group.append(rocket)
    positions = list(range(OLED_HEIGHT, -len(ROCKET_ART) - 1, -BOOT_LAUNCH_PIXELS_PER_FRAME))
    for frame, y in enumerate(positions):
        rocket.y = y
        palette[2] = 0xFFFFFF if frame % 2 == 0 else 0x000000
        _fill_led_chain((frame + 1) / len(positions), BOOT_LAUNCH_COLOR)
        time.sleep(BOOT_LAUNCH_FRAME_SECONDS)
    group.remove(rocket)

    title_text = "KSP MACROPAD"
    group.append(label.Label(terminalio.FONT, text=title_text, x=(OLED_WIDTH - len(title_text) * 6) // 2, y=16))
    time.sleep(BOOT_TITLE_SECONDS)

    # Hand the LEDs back blank; the mod sets real states once connected.
    pixels.fill((0, 0, 0))
    pixels.show()
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

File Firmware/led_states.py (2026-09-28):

# ============================================================================
# KSP MacroPad — LED state constants (CircuitPython)
# Mirrors mod/KSPMacropad/LEDStates.cs — values must stay in sync with it.
# ============================================================================
# NOTE: LEDStates.cs's own per-group comments are stale (reference an old
# macro-key layout). The groupings below use the CURRENT final macro list
# (see project doc's macro table) — the byte VALUES are unchanged from the
# .cs file, only these comments are corrected.

class LEDStates:
    # 0x00 - LAUNCH SEQUENCE
    LAUNCH_IDLE = 0x00
    LAUNCH_EXECUTING = 0x01
    LAUNCH_COMPLETE = 0x02

    # 0x01 - AUTO GRAVITY TURN (AGT)
    AGT_IDLE = 0x00
    AGT_ACTIVE = 0x01

    # 0x02 - CIRCULARIZE SETUP (CIRC)
    CIRC_IDLE = 0x00
    CIRC_UNAVAILABLE = 0x01
    CIRC_CALCULATING = 0x02
    CIRC_WARPING = 0x03
    CIRC_COMPLETE = 0x04

    # 0x03 - TIME ACCEL TO NEXT EVENT
    TIMEACCEL_IDLE = 0x00
    TIMEACCEL_UNAVAILABLE = 0x01
    TIMEACCEL_WARPING = 0x02

    # 0x04 - INTERCEPT CALC
    INTERCEPT_IDLE = 0x00
    INTERCEPT_CALCULATING = 0x01
    INTERCEPT_SOLUTION = 0x02
    INTERCEPT_INSUFFICIENT_DV = 0x03

    # 0x05 - ORBIT SYNC (ORBSYNC)
    ORBSYNC_IDLE = 0x00
    ORBSYNC_CALCULATING = 0x01
    ORBSYNC_EXECUTING = 0x02
    ORBSYNC_COMPLETE = 0x03

    # 0x06 - RENDEZVOUS PREP
    RENDEZVOUS_IDLE = 0x00
    RENDEZVOUS_ACTIVE = 0x01
    RENDEZVOUS_IN_RANGE = 0x02

    # 0x07 - DEORBIT BURN
    DEORBIT_IDLE = 0x00
    DEORBIT_UNAVAILABLE = 0x01
    DEORBIT_PLANNED = 0x02
    DEORBIT_WARPING = 0x03
    DEORBIT_BURNING = 0x04

    # 0x08 - DOCKING PREP (DOCK)
    DOCK_IDLE = 0x00
    DOCK_ACTIVE = 0x01
    DOCK_TARGET_ACQUIRED = 0x02
    DOCK_READY = 0x03

    # 0x09 - LANDING PREP
    LANDING_IDLE = 0x00
    LANDING_CONFIGURING = 0x01
    LANDING_COMPLETE = 0x02

    # 0x0A - SUICIDE BURN ARM
    SUICIDEBURN_IDLE = 0x00
    SUICIDEBURN_ARMED = 0x01
    SUICIDEBURN_IMMINENT = 0x02
    SUICIDEBURN_BURNING = 0x03

    # 0x0B - PRECISION INPUT TOGGLE: onboard-only, no LED states

    # 0x0C - TRANSMIT SCIENCE (SCIENCE)
    SCIENCE_IDLE = 0x00
    SCIENCE_UNAVAILABLE = 0x01
    SCIENCE_TRANSMITTING = 0x02
    SCIENCE_COMPLETE = 0x03

    # 0x0D - RESOURCE MONITOR MODE (RESOURCE)
    RESOURCE_IDLE = 0x00
    RESOURCE_NOMINAL = 0x01
    RESOURCE_LOW = 0x02
    RESOURCE_VERYLOW = 0x03
    RESOURCE_CRITICAL = 0x04
    RESOURCE_DEPLETING = 0x05

    # 0x0E - AUX MODE TOGGLE: onboard-only, no LED states

    # 0x0F - AUTOPILOT
    AUTOPILOT_IDLE = 0x00
    AUTOPILOT_IMPOSSIBLE = 0x01
    AUTOPILOT_READY = 0x02
    AUTOPILOT_PLANNING = 0x03
    AUTOPILOT_EXECUTING = 0x04

    # 0x10-0x13 - UNDERGLOW (all 4 zones share this one group)
    UNDERGLOW_IDLE = 0x00
    UNDERGLOW_CONNECTED_NOVESSEL = 0x01
    UNDERGLOW_LAUNCHPAD = 0x02
    UNDERGLOW_ASCENT = 0x03
    UNDERGLOW_STABLE_ORBIT = 0x04
    UNDERGLOW_TIMEWARP = 0x05
    UNDERGLOW_MANEUVER_IMMINENT = 0x06
    UNDERGLOW_LANDING = 0x07
    UNDERGLOW_AUTOPILOT = 0x08
    UNDERGLOW_CRITICAL_RESOURCE = 0x09
    UNDERGLOW_COMMS_LOST = 0x0A

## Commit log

2026-07-03 kicad files
    [KSPMacroPad.kicad_pcb, KSPMacroPad.kicad_sch]
2026-07-05 put design files in design folder
    [KSPMacroPad.kicad_pcb, KSPMacroPad.kicad_sch]
2026-07-05 removed design files from main
    [KSPMacroPad.kicad_pcb, KSPMacroPad.kicad_sch]
2026-07-05 fixed main branch
    [KSPMacroPad.kicad_pcb, KSPMacroPad.kicad_sch]
2026-07-11 serial communication skeleton
    Serial read loop on background thread, 6-byte packet validation, key and encoder parsing placeholders in Update(). No actual in game actions will occur yet.
2026-07-11 fixed encoder logic
    made it so the logic includes modes that the encoders will be in
2026-07-11 Create LEDStates.cs
    created a class to store the different states each LED can be in
2026-07-11 LED serial communication skeleton
    created the skeleton for communication of data to the board via serial. This created a second packet structure that the board will read and apply to the LEDs
2026-07-11 Update KSPMacroPad.kicad_sch
    fixed naming assignments of diodes so they matches with the switch they are connected to
    [KSPMacroPad.kicad_sch]
2026-07-12 backup KSPMacroPad.kicad_pcb
    doing some schematic fixes and I want to make sure the PCB is backed up before I align it to the schematic fixes
    [KSPMacroPad.kicad_pcb]
2026-07-12 fixed schematic issues
    the previous schematic was terrible, LEDs were still under D# naming which makes it hard when building the PCB. The whole keypad matrix was wrong to and wouldn't actually work in reality because of an oversight I had
    [KSPMacroPad.kicad_sch]
2026-07-12 minor fix
    forgot to put a wire back
    [KSPMacroPad.kicad_sch]
2026-07-12 fixed LED naming
    made LED naming and layout match that of the switches
    [KSPMacroPad.kicad_sch]
2026-07-12 fixed LEDs
    the 5V for the LEDs would circumvent the cap so I had to add nets and ties. I also isolated the LED GND from the other GNDs
    [KSPMacroPad.kicad_sch]
2026-07-12 all components laid out
    [KSPMacroPad.kicad_pcb]
2026-07-12 finished PCB
    routed everything using the FreeRouting plugin, then cleaned up what it couldn't do. I think everything is wired correctly
    [KSPMacroPad.kicad_pcb]
2026-07-13 naming convention fix
    renamed the encoders to match the code in the mod
    [KSPMacroPad.kicad_sch]
2026-07-13 silkscreen and sizine
    fixed the sizing of the PCB and added some silkscreen text so the PCB is easier to configure once I build it irl
    [KSPMacroPad.kicad_pcb]
2026-07-13 current images
    added images of what the project currently looks like
2026-07-13 added M# mounting holes
    [KSPMacroPad.kicad_pcb]
2026-07-13 slight sizing change
    more rounded numbers for the dimensions of the PCB
    [KSPMacroPad.kicad_pcb]
2026-07-14 updated footprints
    [KSPMacroPad.kicad_sch]
2026-07-14 pcb with 3d models
    made it so the 3d version of the PCB now has the 3d models
    [KSPMacroPad.kicad_pcb]
2026-07-14 .step file of PCB
    exported a .step file of the PCB so that I can start working on the case for it.
    [board.step]
2026-07-14 routing fix
    lowk didnt think the routing looked cool enough so I redid it
    [KSPMacroPad.kicad_pcb]
2026-09-26 case files
    [case_bottom.stl, case_top_plate.stl, ksp_macropad_case.scad]
2026-09-26 led assignment
    making sure the led chain is assigned correctly for when LEDs are addressed
    [code.py]
2026-09-26 button debounce
2026-09-26 encoder implementation
    issue spotted with wiring, will have to redo circuit board
    [code.py]
2026-09-26 fixed wrong connection
    encoder was connected to LED_GND
    [KSPMacroPad.kicad_pcb, KSPMacroPad.kicad_sch, freerouting.dsn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]
2026-09-26 encoder logic
2026-09-27 LED work
2026-09-28 led fix
2026-09-28 using JetBrains.Annotations; using System; using System.Collections.Generic; using System.IO.Ports; using System.Threading; using UnityEngine; namespace KSPMacropad { [KSPAddon(KSPAddon.Startup.Fligh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
2026-09-28 Implement simple (one-shot, no vector math) macro bodies
    LAUNCH SEQUENCE, TIME ACCEL TO NEXT EVENT, DOCKING PREP, LANDING PREP,
    SUICIDE BURN ARM (arm step only), TRANSMIT SCIENCE, RESOURCE MONITOR
    MODE toggle. Remaining macros (AUTO GRAVITY TURN, CIRCULARIZE,
    INTERCEPT CALC, ORBIT SYNC, RENDEZVOUS PREP, DEORBIT BURN, AUTOPILOT)
    need maneuver-node vector math or continuous closed-loop control -
    left as stubs, next pass.
2026-09-28 Implement remaining six flight macros with shared node-burn executor
    Adds AUTO GRAVITY TURN, CIRCULARIZE, INTERCEPT CALC, ORBIT SYNC,
    RENDEZVOUS PREP, and DEORBIT BURN. Burn-based macros share one executor
    that warps to 30s before the node, holds throttle until pointed within
    5 deg, tapers over the last 10 m/s, and cancels on a second keypress.
    Only one macro can fly the vessel at a time.
    Orbital math moves into a standalone OrbitMath class and is compiled
    and unit-tested outside KSP (23 checks, including Curtis Example 5.2
    for the Lambert solver). AUTOPILOT's mid-course correction now derives
    its burn direction from the destination's orbital plane instead of
    guessing a sign. SetLEDState di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
2026-09-28 Queue flying macros instead of refusing them while busy
    Pressing AGT, CIRCULARIZE, INTERCEPT, ORBIT SYNC, DEORBIT or AUTOPILOT
    while another of them is flying now queues it. When the running macro
    succeeds the next one starts, planned fresh from the orbit it was left
    in. A failure or cancel clears the queue so a chain never continues
    past a step that didn't happen. Pressing a queued key again removes it;
    pressing the running key cancels it (AUTOPILOT included, which used to
    ignore the second press).
    A queued INTERCEPT plans and flies in one go. Starting any other macro
    drops a planned-but-unflown intercept node, since its orbit is stale.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
2026-09-28 Show macro queue on the OLED and add a boot animation
    Reads the mod's new telemetry IDs (0x17 active macro, 0x18 next queued
    macro, 0x19 queue length) and shows them right-aligned on line 1 as a
    4-char tag, e.g. "CONN M1 CIRC>SYNC+1", only while connected. Line
    1's mode label shortens from "MODE 1" to "M1" to make room. Needs the
    matching mod commit on the mod branch.
    Replaces the static boot splash with a T-3/2/1 countdown, a rocket
    sprite climbing off the top of the screen with a flickering exhaust,
    then the title, while the LEDs fill along the chain (amber, then blue).
    About 3s total. Firmware bumped to 0.3.0.
    Claude-Session: htt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
    [code.py]
2026-09-28 Wire up the encoders
    Encoder packets were parsed and discarded. Now:
    - Mode 1: left adjusts throttle live (2% per click), right steps time
    warp, capped at KSP's own limit for the current altitude.
    - Mode 2: dialed throttle/heading are mirrored from the pad (same
    clamping as the firmware) and applied on the second PRECISION press.
    The heading is held at the current pitch until manual input, landing,
    or a flying macro takes over.
    - Mode 3: left zooms the camera live (clockwise = in), right dials the
    RCS thrust limiter, applied to every RCS module on the second AUX
    press.
    Only dials that were actually turned get applied, so double-tapping a
    mode key never commits the firmware's def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
2026-09-28 Implement SUICIDE BURN: descent monitor and auto-fire
    SUICIDE BURN ARM used to only set a flag. It's now a flying macro, so it
    can be queued (e.g. behind DEORBIT for an airless landing) and a second
    hold of the key disarms it.
    While armed it watches radar altitude against the stopping distance at
    full thrust (total surface speed, current-atmosphere thrust with limiters,
    x1.15 safety + 10 m margin). Inside 2x that height the LED goes IMMINENT
    and SAS swings to surface retrograde; at the trigger height it burns. The
    throttle is set each frame to the deceleration that reaches 2 m/s at the
    margin height, then holds 2 m/s to touchdown. No throttle while pointed
    more than 30 deg off retrograde.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
2026-09-28 Add OLED tag for SUICIDE BURN
    SUICIDE BURN is now a flying macro on the mod side, so it can show up as
    the active or queued macro on line 1. Without a tag it would render as
    "????".
    Claude-Session: https://claude.ai/code/session_01F6PiWiWZqKf4f7h55GQw1S
    [code.py]
2026-09-29 Match the firmware to the PCB
    The matrix has no 3.3 V feed, so each column pin is now driven high in
    turn and the row pins are read as ADCs, with new voltage bands for the
    updated resistor values (R1/R3/R6/R8 0 ohm, R2/R4 10k, R5/R7 16k, all 1%).
    The OLED is on D5/D4 as routed, key ids follow the physical layout, and
    the LED chain map follows the actual chain order on the board.
    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
2026-09-29 Find the pad automatically and reconnect when it drops
    The serial port is no longer hardcoded to COM3. The mod listens on each
    port for the pad's hello packet and uses the one that answers, or the
    port named in KSPMacropad.cfg ("port = COM5") if there is one. Reading
    moved to a background thread with a byte-level packet framer, so a
    dropped or garbled byte no longer throws off every packet after it. If
    the pad is unplugged the mod keeps retrying and resends every LED state
    once it's back.
    The heartbeat now runs on unscaled time so pausing the game doesn't make
    the pad show NO CONN, and a resync request from the pad (type 0x04)
    resends everything.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
2026-09-29 Drive the LED states nothing was setting
    LAUNCH goes green once out of the atmosphere, TIME ACCEL goes back to
    idle when the warp ends, DOCKING PREP goes green within 20 m at under
    0.5 m/s, LANDING PREP goes green on touchdown, and TRANSMIT SCIENCE goes
    green when the transmitter finishes. AUTOPILOT shows READY or IMPOSSIBLE
    for the current target before it's pressed, rechecked on target change
    and every 30 s.
    RESOURCE MONITOR now totals each resource across the whole vessel,
    skips IntakeAir, Ore and locked tanks, and shows DEPLETING when anything
    would run dry within 30 s. It used GetActiveResources(), which doesn't
    exist in KSP 1.x.
    Underglow now shows COMMS LOST, MANEUVER IMMINENT (node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
2026-09-29 Send the warp rate instead of the warp index
    The pad showed the rate index, which means nothing without the rate
    tables. The telemetry now carries the actual multiplier as mantissa and
    power of ten, with a flag for physics warp.
    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
2026-09-29 Pulse urgent LEDs, show warp rate and rendezvous speed
    SUICIDE BURN armed/imminent, RESOURCE critical/depleting, AUTOPILOT
    executing and the critical underglow states pulse instead of holding
    solid, faster when more urgent. RENDEZVOUS PREP fades toward red as the
    closing speed rises. The OLED shows the warp as a rate ("1000x", "P4x"
    for physics warp). LEDs clear when the mod goes silent. Works with the
    CircuitPython 9 display bus API and falls back on 8.
    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
    [code.py]
2026-09-29 fixed resistors
    [KSPMacroPad.kicad_sch]
2026-09-29 Update PCB
    fixed the sizing and made it match the schematic
    [KSPMacroPad.kicad_pcb, board.step, freerouting.dsn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]
2026-09-29 actually matches schematic
    [KSPMacroPad.kicad_pcb, board.step, freerouting.dsn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]
2026-09-29 design files
    [case_bottom.step, case_bottom.stl, case_top_plate.step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]
2026-09-29 Restructure repo for Stardance submission
    [KSPMacroPad-B_Cu.gbr, KSPMacroPad-B_Mask.gbr, KSPMacroPad-B_Paste.gbr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]
2026-09-29 updated something
    [KSPMacroPad.kicad_pcb]
2026-09-29 Update README with case, mod, protocol and BOM
    Adds case, exploded and assembled renders, explains the analog
    matrix, documents the mod and the current serial protocol, fixes
    the OLED pins (D4/D5), and adds the bill of materials.
    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
